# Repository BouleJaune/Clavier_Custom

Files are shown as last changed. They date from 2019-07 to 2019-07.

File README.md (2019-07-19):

# Clavier_Custom

Création d'un clavier avec un layout custom à partir de zéro.

Keyboard-layout.png et Raw_Layout_Data.txt représente le layout qui sera utilisé, généré via KLE.

CAD Case contient les fichiers .DXF pour découper les plaques d'aluminium qui serviront de "boitier".

CAD PCB contient le PCB exporté en .DXF pour comparer le placement des pas de vis avec le PCB.

PCB_vs_plaque.blender est le fichier blender permettant de voir qu'il n'y aura pas de soucis vis à vis des vis entrant en contact avec le PCB.

Scripting_Kicad contient les coordonnées des diodes et switchs sur le PCB ainsi qu'un petit script .py pour les placer automatiquement dans Kicad.

Kicad contient les librairies utilisées ainsi que le projet Kicad (PCB et& schématique).

Encore une hésitation sur l'utilisation d'une simple Teensy++ 2.0 ou alors la création complète du micro-contrôleur ce qui implique de burn un bootloader et gérer les soudures complexes.

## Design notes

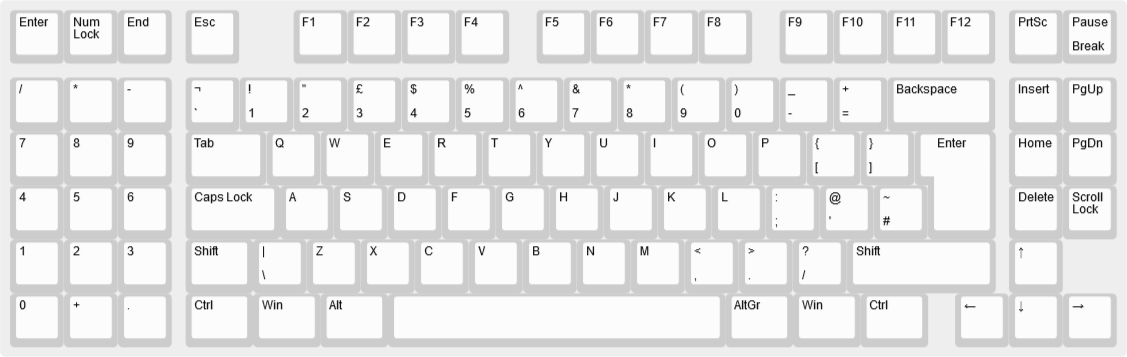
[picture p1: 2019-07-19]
keyboard-layout.png

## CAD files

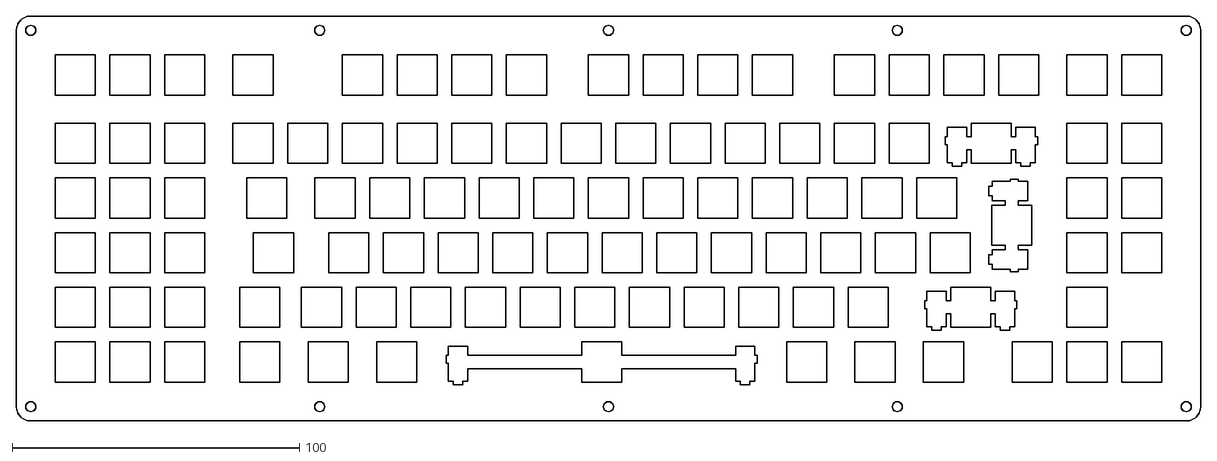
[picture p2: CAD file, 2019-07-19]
CAD Case/Switch_Layer.dxf
412.5 x 141.1

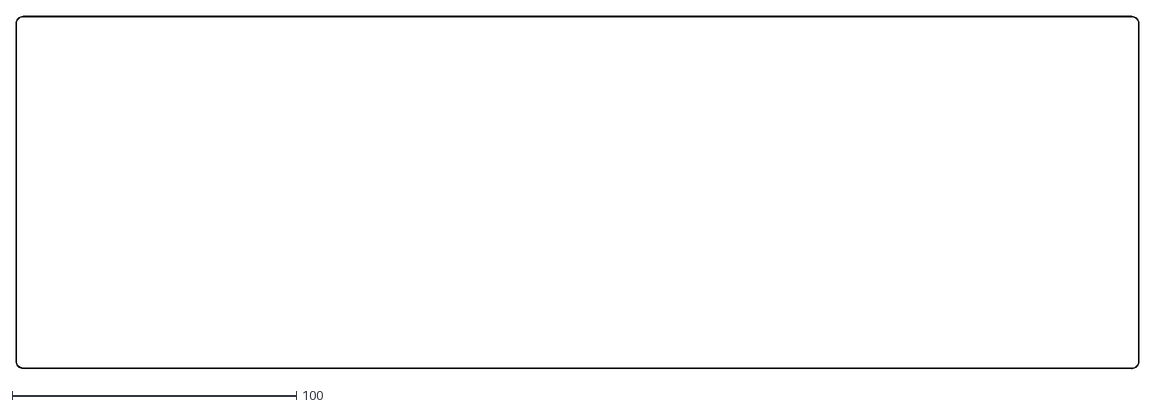
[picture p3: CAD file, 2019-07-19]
CAD PCB/Clavier-Edge_Cuts.dxf
395.4 x 123.9

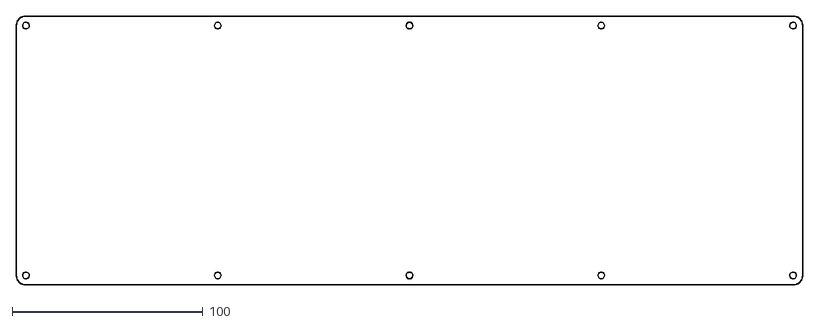
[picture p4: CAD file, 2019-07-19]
CAD Case/Bottom_Layer.dxf
412.5 x 141.1

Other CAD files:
CAD PCB/Clavier-B_Mask.dxf
CAD PCB/Clavier-B_Paste.dxf
CAD PCB/Clavier-F_Mask.dxf
CAD PCB/Clavier-F_Paste.dxf
PCB_vs_plaque.blend

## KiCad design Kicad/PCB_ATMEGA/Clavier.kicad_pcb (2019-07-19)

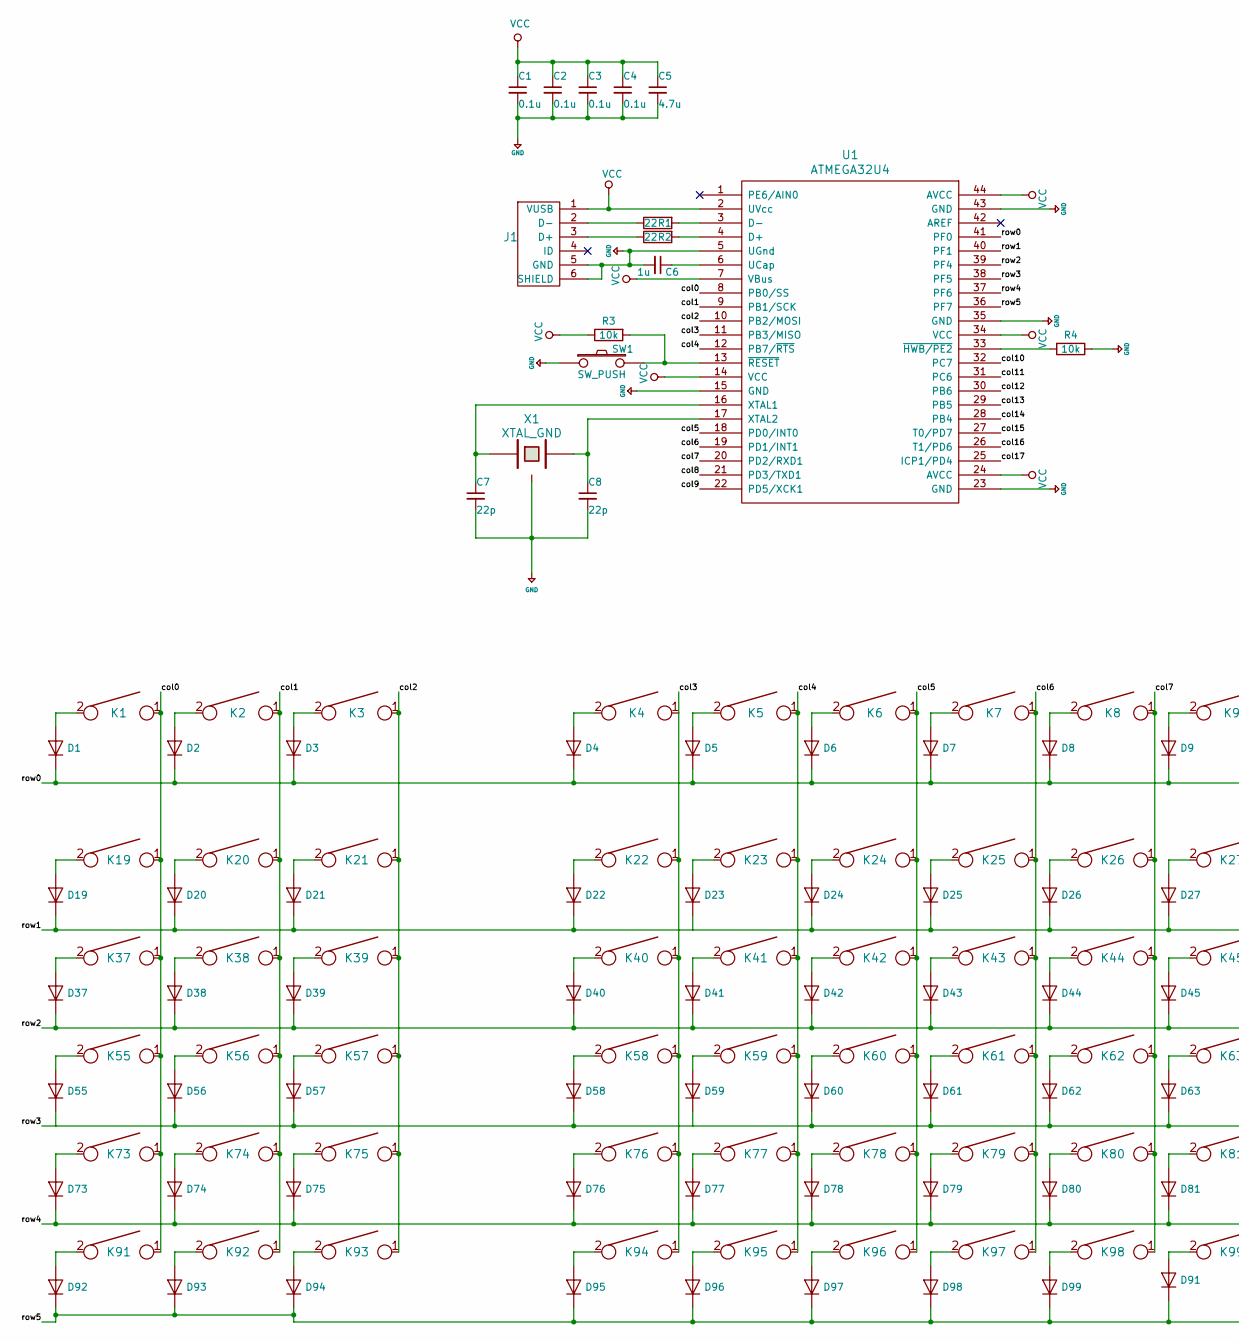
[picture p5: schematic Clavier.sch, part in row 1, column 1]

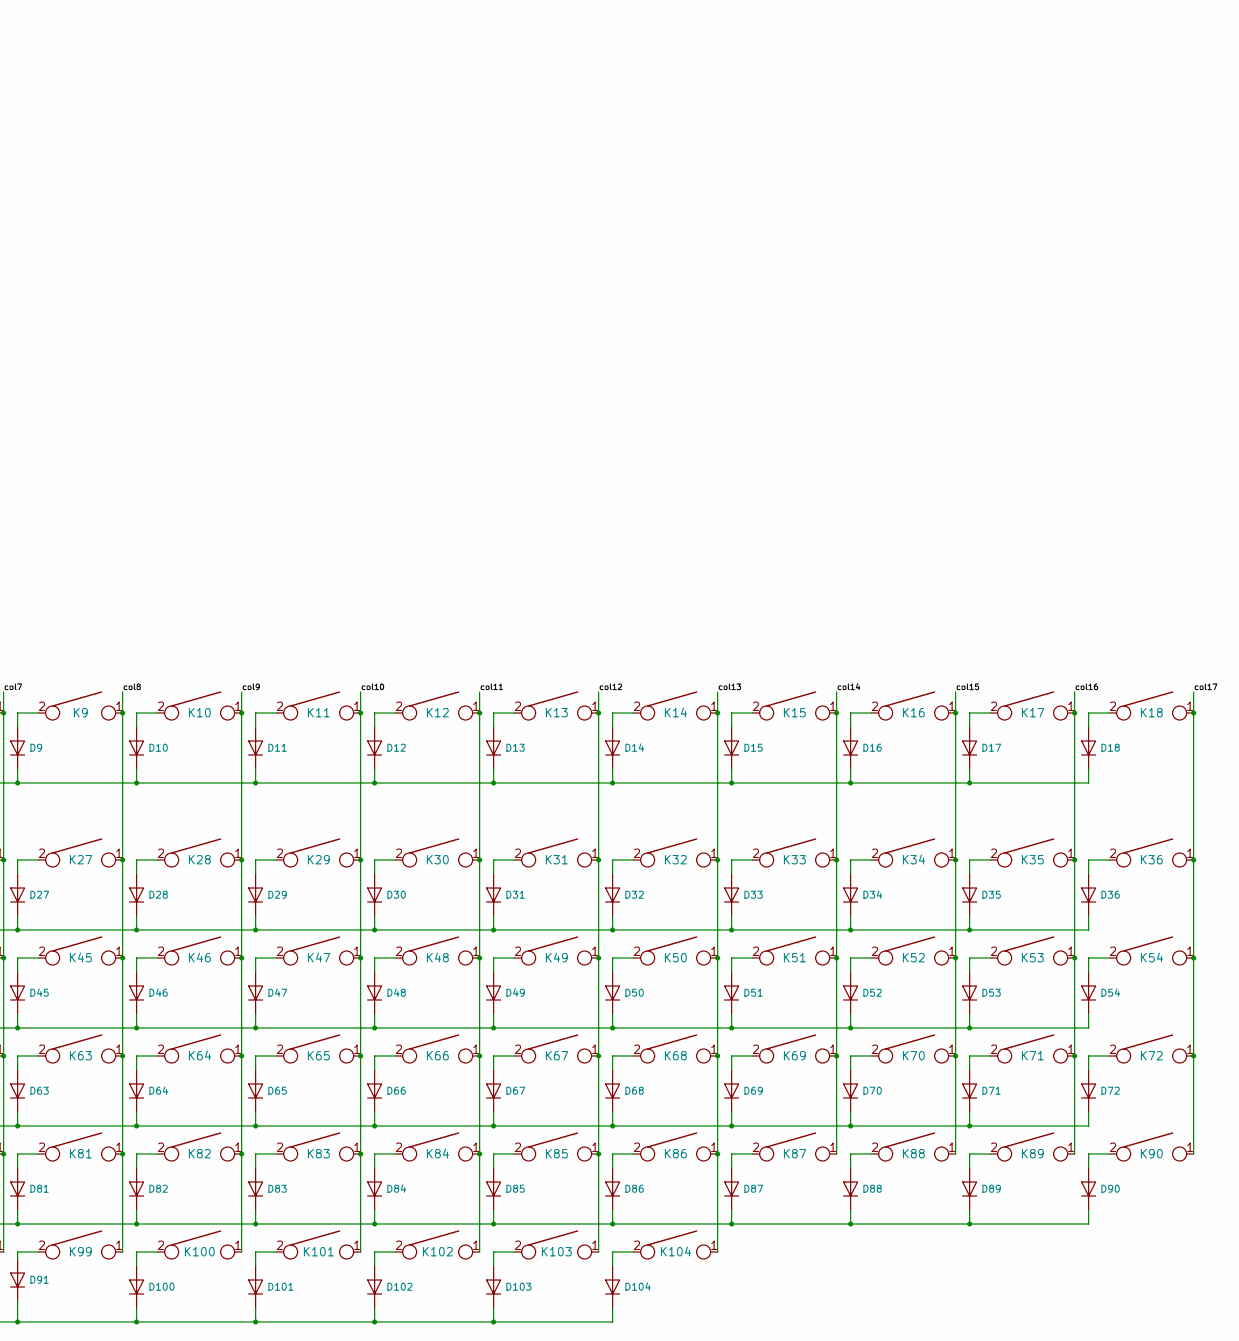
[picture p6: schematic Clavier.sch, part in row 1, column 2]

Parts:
C1, C2, C3, C4: 0.1u; C_0805_2012Metric_Pad1.15x1.40mm_HandSolder
C5: 4.7u; C_0805_2012Metric_Pad1.15x1.40mm_HandSolder
C6: 1u; C_0805_2012Metric_Pad1.15x1.40mm_HandSolder
C7, C8: 22p; C_0805_2012Metric_Pad1.15x1.40mm_HandSolder
D1, D2, D3, D4, D5, D6, D7, D8, D9, D10, D11, D12, D13, D14, D15, D16, D17, D18, D19, D20, D21, D22, D23, D24, D25, D26, D27, D28, D29, D30, D31, D32, D33, D34, D35, D36, D37, D38, D39, D40, D41, D42, D43, D44, D45, D46, D47, D48, D49, D50, D51, D52, D53, D54, D55, D56, D57, D58, D59, D60, D61, D62, D63, D64, D65, D66, D67, D68, D69, D70, D71, D72, D73, D74, D75, D76, D77, D78, D79, D80, D81, D82, D83, D84, D85, D86, D87, D88, D89, D90, D91, D92, D93, D94, D95, D96, D97, D98, D99, D100, D101, D102, D103, D104: D; D_SOD123_axial
J1: USB_mini_micro_B; USB_miniB_hirose_5S8
K1, K2, K3, K4, K5, K6, K7, K8, K9, K10, K11, K12, K13, K14, K15, K16, K17, K18, K19, K20, K21, K22, K23, K24, K25, K26, K27, K28, K29, K30, K31, K32, K33, K34, K35, K36, K37, K38, K39, K40, K41, K42, K43, K44, K45, K46, K47, K48, K49, K50, K51, K52, K53, K54, K55, K56, K57, K58, K59, K60, K61, K62, K63, K64, K65, K66, K67, K68, K69, K70, K71, K72, K73, K74, K75, K76, K77, K78, K79, K80, K81, K82, K83, K84, K85, K86, K87, K88, K89, K90, K91, K92, K93, K94, K95, K96, K97, K98, K99, K100, K101, K102, K103, K104: KEYSW; Mx_Alps_100
R1, R2: 22; R_0805_2012Metric_Pad1.15x1.40mm_HandSolder
R3, R4: 10k; R_0805_2012Metric_Pad1.15x1.40mm_HandSolder
SW1: SW_PUSH; SW_SPST_TL3342
U1: ATMEGA32U4; TQFP-44_10x10mm_P0.8mm
X1: XTAL_GND; FA-238

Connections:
+5V: C1.2, C2.2, C3.2, C4.2, C5.2, C6.2, C7.2, C8.2, J1.5 (GND), J1.6 (SHIELD), R4.1, SW1.1, U1.5 (UGnd), U1.15 (GND), U1.23 (GND), U1.35 (GND), U1.43 (GND), X1.3
/col0: K1.1, K19.1, K37.1, K55.1, K73.1, K91.1, U1.8 (PB0/SS)
/col1: K2.1, K20.1, K38.1, K56.1, K74.1, K92.1, U1.9 (PB1/SCK)
/col2: K3.1, K21.1, K39.1, K57.1, K75.1, K93.1, U1.10 (PB2/MOSI)
/col3: K4.1, K22.1, K40.1, K58.1, K76.1, K94.1, U1.11 (PB3/MISO)
/col4: K5.1, K23.1, K41.1, K59.1, K77.1, K95.1, U1.12 (PB7/~RTS)
/col5: K6.1, K24.1, K42.1, K60.1, K78.1, K96.1, U1.18 (PD0/INT0)
/col6: K7.1, K25.1, K43.1, K61.1, K79.1, K97.1, U1.19 (PD1/INT1)
/col7: K8.1, K26.1, K44.1, K62.1, K80.1, K98.1, U1.20 (PD2/RXD1)
/col8: K9.1, K27.1, K45.1, K63.1, K81.1, K99.1, U1.21 (PD3/TXD1)
/col9: K10.1, K28.1, K46.1, K64.1, K82.1, K100.1, U1.22 (PD5/XCK1)
/col10: K11.1, K29.1, K47.1, K65.1, K83.1, K101.1, U1.32 (PC7)
/col11: K12.1, K30.1, K48.1, K66.1, K84.1, K102.1, U1.31 (PC6)
/col12: K13.1, K31.1, K49.1, K67.1, K85.1, K103.1, U1.30 (PB6)
/col13: K14.1, K32.1, K50.1, K68.1, K86.1, K104.1, U1.29 (PB5)
/col14: K15.1, K33.1, K51.1, K69.1, K87.1, U1.28 (PB4)
/col15: K16.1, K34.1, K52.1, K70.1, K88.1, U1.27 (T0/PD7)
/col16: K17.1, K35.1, K53.1, K71.1, K89.1, U1.26 (T1/PD6)
/col17: K18.1, K36.1, K54.1, K72.1, K90.1, U1.25 (ICP1/PD4)
/row0: D1.1 (K), D2.1 (K), D3.1 (K), D4.1 (K), D5.1 (K), D6.1 (K), D7.1 (K), D8.1 (K), D9.1 (K), D10.1 (K), D11.1 (K), D12.1 (K), D13.1 (K), D14.1 (K), D15.1 (K), D16.1 (K), D17.1 (K), D18.1 (K), U1.41 (PF0)
/row1: D19.1 (K), D20.1 (K), D21.1 (K), D22.1 (K), D23.1 (K), D24.1 (K), D25.1 (K), D26.1 (K), D27.1 (K), D28.1 (K), D29.1 (K), D30.1 (K), D31.1 (K), D32.1 (K), D33.1 (K), D34.1 (K), D35.1 (K), D36.1 (K), U1.40 (PF1)
/row2: D37.1 (K), D38.1 (K), D39.1 (K), D40.1 (K), D41.1 (K), D42.1 (K), D43.1 (K), D44.1 (K), D45.1 (K), D46.1 (K), D47.1 (K), D48.1 (K), D49.1 (K), D50.1 (K), D51.1 (K), D52.1 (K), D53.1 (K), D54.1 (K), U1.39 (PF4)
/row3: D55.1 (K), D56.1 (K), D57.1 (K), D58.1 (K), D59.1 (K), D60.1 (K), D61.1 (K), D62.1 (K), D63.1 (K), D64.1 (K), D65.1 (K), D66.1 (K), D67.1 (K), D68.1 (K), D69.1 (K), D70.1 (K), D71.1 (K), D72.1 (K), U1.38 (PF5)
/row4: D73.1 (K), D74.1 (K), D75.1 (K), D76.1 (K), D77.1 (K), D78.1 (K), D79.1 (K), D80.1 (K), D81.1 (K), D82.1 (K), D83.1 (K), D84.1 (K), D85.1 (K), D86.1 (K), D87.1 (K), D88.1 (K), D89.1 (K), D90.1 (K), U1.37 (PF6)
/row5: D91.1 (K), D92.1 (K), D93.1 (K), D94.1 (K), D95.1 (K), D96.1 (K), D97.1 (K), D98.1 (K), D99.1 (K), D100.1 (K), D101.1 (K), D102.1 (K), D103.1 (K), D104.1 (K), U1.36 (PF7)
unnamed: C6.1, U1.6 (UCap)
unnamed: C7.1, U1.16 (XTAL1), X1.1
unnamed: C8.1, U1.17 (XTAL2), X1.2
unnamed: D1.2 (A), K1.2
unnamed: D2.2 (A), K2.2
unnamed: D3.2 (A), K3.2
unnamed: D4.2 (A), K4.2
unnamed: D5.2 (A), K5.2
unnamed: D6.2 (A), K6.2
unnamed: D7.2 (A), K7.2
unnamed: D8.2 (A), K8.2
unnamed: D9.2 (A), K9.2
unnamed: D10.2 (A), K10.2
unnamed: D11.2 (A), K11.2
unnamed: D12.2 (A), K12.2
unnamed: D13.2 (A), K13.2
unnamed: D14.2 (A), K14.2
unnamed: D15.2 (A), K15.2
unnamed: D16.2 (A), K16.2
unnamed: D17.2 (A), K17.2
unnamed: D18.2 (A), K18.2
unnamed: D19.2 (A), K19.2
unnamed: D20.2 (A), K20.2
unnamed: D21.2 (A), K21.2
unnamed: D22.2 (A), K22.2
unnamed: D23.2 (A), K23.2
unnamed: D24.2 (A), K24.2
unnamed: D25.2 (A), K25.2
unnamed: D26.2 (A), K26.2
unnamed: D27.2 (A), K27.2
unnamed: D28.2 (A), K28.2
unnamed: D29.2 (A), K29.2
unnamed: D30.2 (A), K30.2
unnamed: D31.2 (A), K31.2
unnamed: D32.2 (A), K32.2
unnamed: D33.2 (A), K33.2
unnamed: D34.2 (A), K34.2
unnamed: D35.2 (A), K35.2
unnamed: D36.2 (A), K36.2
unnamed: D37.2 (A), K37.2
unnamed: D38.2 (A), K38.2
unnamed: D39.2 (A), K39.2
unnamed: D40.2 (A), K40.2
unnamed: D41.2 (A), K41.2
unnamed: D42.2 (A), K42.2
unnamed: D43.2 (A), K43.2
unnamed: D44.2 (A), K44.2
unnamed: D45.2 (A), K45.2
unnamed: D46.2 (A), K46.2
unnamed: D47.2 (A), K47.2
unnamed: D48.2 (A), K48.2
unnamed: D49.2 (A), K49.2
unnamed: D50.2 (A), K50.2
unnamed: D51.2 (A), K51.2
unnamed: D52.2 (A), K52.2
unnamed: D53.2 (A), K53.2
unnamed: D54.2 (A), K54.2
unnamed: D55.2 (A), K55.2
unnamed: D56.2 (A), K56.2
unnamed: D57.2 (A), K57.2
unnamed: D58.2 (A), K58.2
unnamed: D59.2 (A), K59.2
unnamed: D60.2 (A), K60.2
unnamed: D61.2 (A), K61.2
unnamed: D62.2 (A), K62.2
unnamed: D63.2 (A), K63.2
unnamed: D64.2 (A), K64.2
unnamed: D65.2 (A), K65.2
unnamed: D66.2 (A), K66.2
unnamed: D67.2 (A), K67.2
unnamed: D68.2 (A), K68.2
unnamed: D69.2 (A), K69.2
unnamed: D70.2 (A), K70.2
unnamed: D71.2 (A), K71.2
unnamed: D72.2 (A), K72.2
unnamed: D73.2 (A), K73.2
unnamed: D74.2 (A), K74.2
unnamed: D75.2 (A), K75.2
unnamed: D76.2 (A), K76.2
unnamed: D77.2 (A), K77.2
unnamed: D78.2 (A), K78.2
unnamed: D79.2 (A), K79.2
unnamed: D80.2 (A), K80.2
unnamed: D81.2 (A), K81.2
unnamed: D82.2 (A), K82.2
unnamed: D83.2 (A), K83.2
unnamed: D84.2 (A), K84.2
unnamed: D85.2 (A), K85.2
unnamed: D86.2 (A), K86.2
unnamed: D87.2 (A), K87.2
unnamed: D88.2 (A), K88.2
unnamed: D89.2 (A), K89.2
unnamed: D90.2 (A), K90.2
unnamed: D91.2 (A), K99.2
unnamed: D92.2 (A), K91.2
unnamed: D93.2 (A), K92.2
unnamed: D94.2 (A), K93.2
unnamed: D95.2 (A), K94.2
unnamed: D96.2 (A), K95.2
unnamed: D97.2 (A), K96.2
unnamed: D98.2 (A), K97.2
unnamed: D99.2 (A), K98.2
unnamed: D100.2 (A), K100.2
unnamed: D101.2 (A), K101.2
unnamed: D102.2 (A), K102.2
unnamed: D103.2 (A), K103.2
unnamed: D104.2 (A), K104.2
unnamed: J1.2 (D-), R1.1
unnamed: J1.3 (D+), R2.1
unnamed: R1.2, U1.3 (D-)
unnamed: R2.2, U1.4 (D+)
unnamed: R3.2, SW1.2, U1.13 (~RESET)
unnamed: R4.2, U1.33 (~HWB/PE2)
VCC: C1.1, C2.1, C3.1, C4.1, C5.1, J1.1 (VUSB), R3.1, U1.2 (UVcc), U1.7 (VBus), U1.14 (VCC), U1.24 (AVCC), U1.34 (VCC), U1.44 (AVCC)

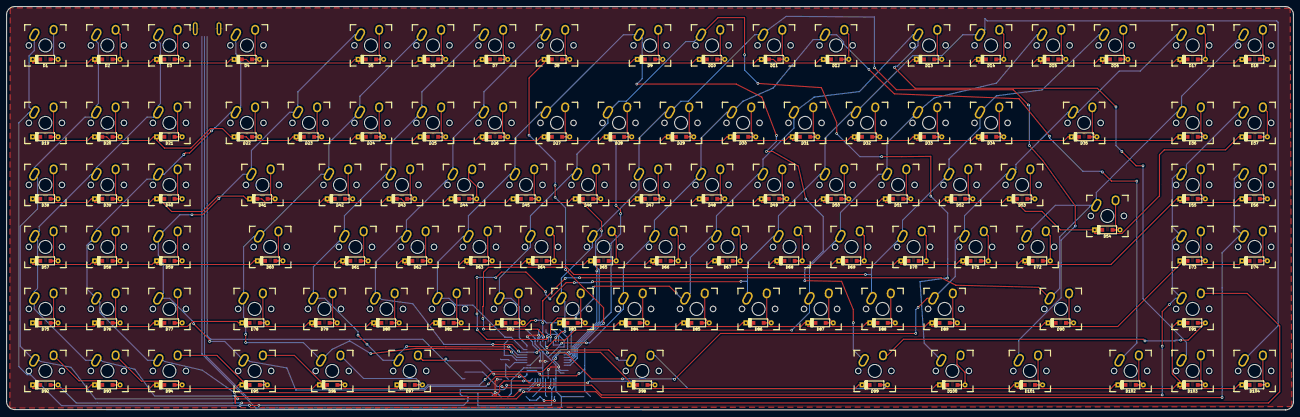
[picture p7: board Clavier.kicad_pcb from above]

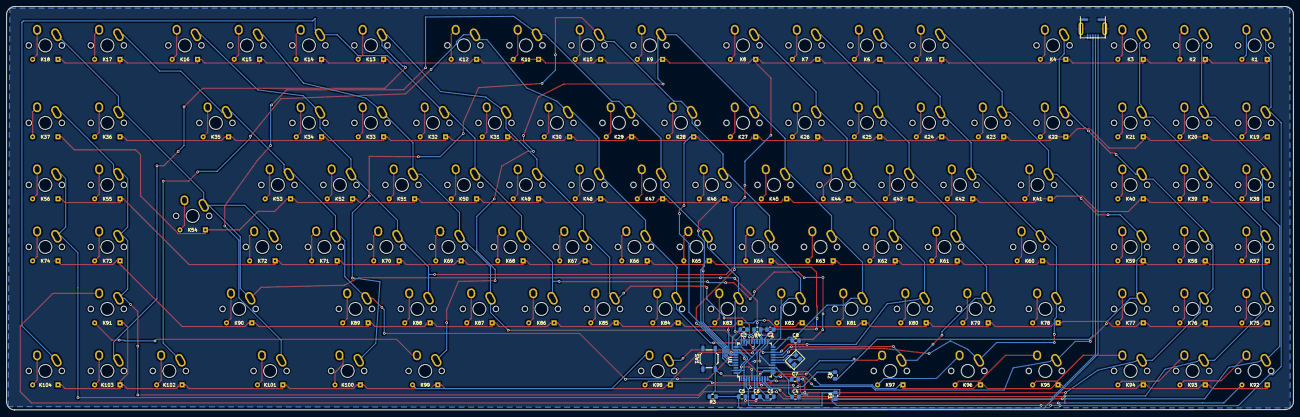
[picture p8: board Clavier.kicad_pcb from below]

Board: 2 copper layers, 395.3 x 123.9 mm, 224 parts (16 on the bottom side), 139 nets.

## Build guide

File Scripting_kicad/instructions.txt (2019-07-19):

Simplement mettre les fichiers dans le répertoire du projet Kicad, 
fermer Kicad et lancer le .kicad_pcb. Cela lancera automatiquement le script
